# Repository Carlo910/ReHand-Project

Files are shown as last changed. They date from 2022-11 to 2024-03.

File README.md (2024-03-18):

# AY2223_I_Project-3

Re-Hand Versione 1.0 13/02/2023

***
Short Description:

Re-Hand is a device that uses 4 flex sensors, mounted on a glove, to recognize gestures. It is designed to be used in rehabilitation, to train subjects who experience problems in perfoming the "grasping" movement. Rehabilitation is done through repetition of the "grasping" gesture by playing a game by carrying out precise instructions given on the screen.
Breve descrizione:

Itlian version: 
Re-Hand è un dispositivo che utilizza 4 flex sensors, montati su di un guanto, per riconoscere dei gesti. 
E' stato pensato per essere utilizzato in ambito riabilitativo, per allenare soggetti che riscontrano problemi nel perfomare il
movimento del "grasping". 
La riabilitazione viene effettuata tramite la ripetizione del gesto del "grasping" svolgendo un gioco eseguendo precise istruzioni fornite a schermo. 

***

Hardware:

A glove is used on which four flex sensors, from thumb to ring finger, are sewn onto the top of the fingers. To read the value measured by the sensors, four voltage dividers (one for each sensor) were made with four 2 kOhm resistors. A PSoC 5LP Dev Kit CY8CKIT-059 was used as the microcontroller. The device was designed as a wearable, so it is equipped with a bluetooth module for sensor data communication and a 3.7 V lipo battery for power supply, with an attached charging circuit.  A 3.3 V linear stabilizer was added to provide the microcontroller with a stabilized voltage, while the Bluetooth gets an unstabilized voltage since the minimum voltage required to power it is 3.6 V.
To check the battery charge level, two identical 1 kOhm resistors were added to read the drop voltage across them.
After prototyping the device, a PCB was made into which all components were soldered. See the 'Eagle' folder to view the model made for printing the PCB.  A case was made thanks to a 3D printer to contain all the hardware components (apart from the sensors and glove). In the 'SolidWorks' folder you can find the model made for printing. It is possible to conveniently turn the device on and off by pressing a switch on the top side of the case. To monitor the bluetooth connection, the user can refer to a red LED located on the side of the case, which flashes at a frequency of 0.2 Hz during bluetooth connection and turns solid once the connection is successfully occurred.

***
PsoC Creator 
The Psoc Creator IDE (Integrated Design Environment) was used to develop the project from the firmware side. 
Within the 'PSOC' folder can be found the 'Project3' workspace which contains the 'Project3' project where the code used to sample the data, average it and finally send it via Bluetooth to the connected device. 
For data sampling, the frequency of the interrupt timer was set to 10 Hz. Once a piece of data is received, it waits to have 10 samples in order to average them and then send them. In addition, every minute the
the battery charge value and then sent. Also managed within the code is the Bluetooth connection and its Led to display whether it has taken place (Led on) or not (Led flashes at 0.2 Hz). In addition, there is the project 'Project3_dataset' which was used to build the datasets for the development of the classifier. A different code is used to make data collection easier by simplifying the connection with the  device that receives the data.

***

Python

To use Re-Hand you need version 3.9 with various libraries to install on your virtual enviroment.
See the file 'requirements.txt' in the folder and run it in your virtual  
environment to install all the required libraries with their respective versions.
 
Upon launching the GUI.py code, the name of the Re-Hand project appears on the screen and the user will be asked to enter their name, thanks to which it will be possible to save performance data from different users. Next, the user can click  a start button, which allows the start of sampling the values of the four variable resistors. In case the user has not entered the name, he/she will not be able to access the second screen and an error message will be displayed on asscreen. Once the start button is pressed, a new screen is opened where the user can choose whether to play the game, or display on the screen some statistical data on the improvement in playing it. 

Thanks to a classifier, specifically a Random Forest, the device can recognize six gestures in total, three used to move through the different GUI windows and three for the rehabilitation task. In the file 'classification_6gestures.ipynb' it is possible to see how the model used for the classification of the gestures. The files 'dataset_training_6gesti.csv' and 'dataset_test_6gesti.csv' contain all the data used to
train and test the model which were collected using the code 'code_dataset.py'. In the file 'rf_model_6gesti.pkl' is saved the model trained on the datasets mentioned above and used to perform real-time prediction for gesture recognition while using the application.

By raising only the index finger (target 4), one enters the game window. At this point the user can start performing the gesture
of grasping, starting with the hand fully open (target 0), then trying to close it halfway (target 1) and finally closing the fist completely (target 2). While performing these gestures, the user will be able to see on the screen an image of a bow being drawn, progressively as the hand closes, until an arrow is fired. Once the game is finished, the time it took the user to complete the gesture is printed on the screen. In the event that the exercise is not performed correctly (time taken longer than 30 seconds) a message will be displayed on the screen a message inviting the user to exit the game and try again. By raising only the thumb while keeping the hand closed (target 3), you will exit the game screen and return to the main Home screen. 

At this point, by raising both index and average (target 5) you can enter the statistics screen, where a graph can be displayed on the screen showing the times in seconds in which the user has done the last ten exercises, if any, with the respective date so that any improvements can be visualized. The display of statistics is allowed only if the user has completed the game at least twice, otherwise an error message appears on the screen. The following graph also shows failed attempts by reporting a time of 30 seconds (the maximum attainable value), highlighted on the graph by a red line. The user's best result, absolute worst result (in case of success) and the number of failed attempts are also displayed. By raising only the thumb while keeping the hand closed (target 3), you exit the game screen to return to the main Home screen. 

***

Italian version:

Hardware:
Si utilizza un guanto su cui sono cuciti quattro flex sensors, dal pollice all'anulare, sulla parte superiore delle dita. Per leggere
il valore misurato dai sensori sono stati realizzati 4 partitori di tensione (uno per ogni sensore) con 4 resistenze da 2 kOhm.
Come microcontrollore è stato usato un PSoC 5LP Dev Kit CY8CKIT‐059.  
Il device è stato pensato come wearble, per cui è dotato di modulo bluetooth per la comunicazione dei dati dei sensori e di una batteria lipo a 3.7 V per
l'alimentazione, con annesso circuito di ricarica. 
E' stato aggiunto uno stabilizzatore lineare a 3.3 V per fornire al microcontrollore una tensione stabilizzata, mentre al modulo
bluetooth arriva una tensione non stabilizzata poichè la minima tensione richiesta per alimentarlo è di 3.6 V.
Per controllare il livello di carica della batteria sono state aggiunte due resistenze identiche da 1 kOhm per leggere la caduta
di tensione su di esse.
Dopo aver realizzato il dispositivo in via prototipale è stata realizzata una PCB in cui sono stati saldati tutti i componenti.
Vedere la cartella 'Eagle' per visualizzare il modello realizzato per la stampa della PCB. 
Per contenere tutti i componenti hardware (a parte i sensori e guanto) è stato realizzato un case grazie ad una stampante 3D. Nella
cartella 'SolidWorks' è possibile trovare la realizzazione del modello per la stampa.
E' possibile accendere e spegnere comodamente il dispositivo premendo un interruttore posto sul lato superiore del case.
Per monitorare la connessione del bluetooth, l'utente può fare riferimento a un led rosso posizionato lateralmente al case, il quale
lampeggia a una frequenza di 0,2 Hz durante la connessione del bluetooth e diventa fisso una volta che la connessione è correttamente
avvenuta.

***

PsoC Creator 
E' stato utilizzato il Psoc Creator IDE (Integrated Design Environment) per sviluppare il progetto dal lato firmware. 
All'interno della cartella 'PSOC' si può trovare il workspace 'Project3' il quale contiene il progetto 'Project3' dove si trova il 
codice utilizzato per campionare i dati, mediarli e infine inviarli tramite Bluetooth al dispositivo connesso. 
Per il campionamento dei dati è stata impostata la frequenza del timer dell'interrupt a 10 Hz. Una volta ricevuto un dato si attende
di avere 10 campioni per poter calcolare la media di questi ultimi e successivamente inviarli. In aggiunta ogni minuto viene misurato
il valore di carica della batteria e poi inviato.
All'interno del codice è gestita anche la connessione del Bluetooth e il relativo Led per visualizzare se è avvenuta (Led acceso)
oppure no (Led lampeggia a 0,2 Hz).
Inoltre è presente il progetto 'Project3_dataset' il quale è stato usato per la realizzazione dei dataset per lo sviluppo del 
classificatore. Viene usato un codice diverso per rendere la raccolta dei dati più agevole semplificando la connessione con il 
dispositivo che riceve i dati.

***

Python

Per utilizzare Re-Hand è necessaria la versione 3.9 con varie librerie da installare sul prorpio virtual enviroment.
Vedere nella cartella il file 'requirements.txt' e eseguirlo nel prorpio virtual  
environment per installare tutte le librerie necessarie con le rispettive versioni.
 
Lanciando il codice GUI.py appare a schermo il nome del progetto Re-Hand e verrà chiesto all'utente di inserire il proprio 
nome, grazie al quale sarà possibile salvare i dati delle prestazioni di diversi utenti. In seguito l'utente può cliccare 
un pulsante di start, che permette l'inizio del campionamento dei valori delle quattro resistenze variabili.
Nel caso in cui l'utente non abbia inserito il nome, non potrà accedere alla seconda schermata e verrà visualizzato a aschermo un messaggio di errore.
Una volta premuto il pulsante di start, viene aperta una nuova schermata dove l'utente può scegliere se svolgere il gioco, 
oppure visualizzare a schermo alcuni dati statistici sul miglioramento nello svolgimento dello stesso.

Grazie a un classificatore, in particolare un Random Forest, il dispositivo riesce a riconoscere sei gesti in totale,
tre utilizzati per muoversi attraverso le diverse finestre della GUI e tre per l'attività di riabilitazione.
Nel file 'classification_6gesti.ipynb' è possibile visualizzare come è stato realizzato il modello usato per la
classificatione dei gesti. I files 'dataset_training_6gesti.csv' e 'dataset_test_6gesti.csv' contengono tutti i dati usati per
allenare e testare il modello i quali sono stati raccolti utilizzando il codice 'codice_dataset.py'. Nel file 'rf_model_6gesti.pkl' è
salvato il modello allenato sui dataset citati sopra e usato per compiere la predizione i tempo reale per il riconoscimento dei gesti
durante l'utilizzo dell'applicazione.

Alzando solo l'indice (target 4), si entra nella finestra del gioco. A questo punto l'utente può iniziare a performare il gesto
del grasping, partendo con la mano completamente aperta (target 0), provando poi a chiuderla a metà (target 1) e infine
chiudendo completamente il pugno (target 2). Durante l'esecuzione di questi gesti, l'utente potrà visualizzare a schermo
l'immagine di un arco che viene tirato, progressivamente alla chiusura della mano, fino a scoccare una freccia. 
Una volta finito il gioco viene stampato a schermo il tempo che l'utente ha impiegato per completare il gesto.
Nel caso in cui l'esercizio non venga svolto correttamente (tempo di svolgimento superiore a 30 secondi) verrà visualizzato 
a schermo un messaggio che inviterà l'utente a uscire dal gioco e a riprovare. Alzano solo il pollice mantenendo la mano chiusa
(target 3), si esce dalla schermata del gioco per tornare nella schermata Home principale. 
 
A questo punto, alzando sia indice che medio (target 5) è possibile entrare nella schermata delle statistiche,
dove si può visualizzare a schermo un grafico che mostra i tempi in secondi in cui l'utente ha svolto gli ultimi dieci l'esercizi, se presenti, con la rispettiva
data in modo da poter visualizzare gli eventuali miglioramenti. La visualizzazione delle statistiche viene permessa solo se
l'utente ha completato almeno due volte il gioco, in caso contrario appare a schermo un messaggio di errore.
Il seguente grafico inoltre mostra anche i tentativi falliti riportando un tempo di 30 secondi (il massimo valore raggiungibile),
evidenziato sul grafico da una linea rossa.
Vengono inoltre visualizzati il risultato migliore, quello peggiore in assoluto dell'utente (in caso di successo) e il numero di tentativi falliti.
Alzano solo il pollice mantenendo la mano chiusa
(target 3), si esce dalla schermata del gioco per tornare nella schermata Home principale.

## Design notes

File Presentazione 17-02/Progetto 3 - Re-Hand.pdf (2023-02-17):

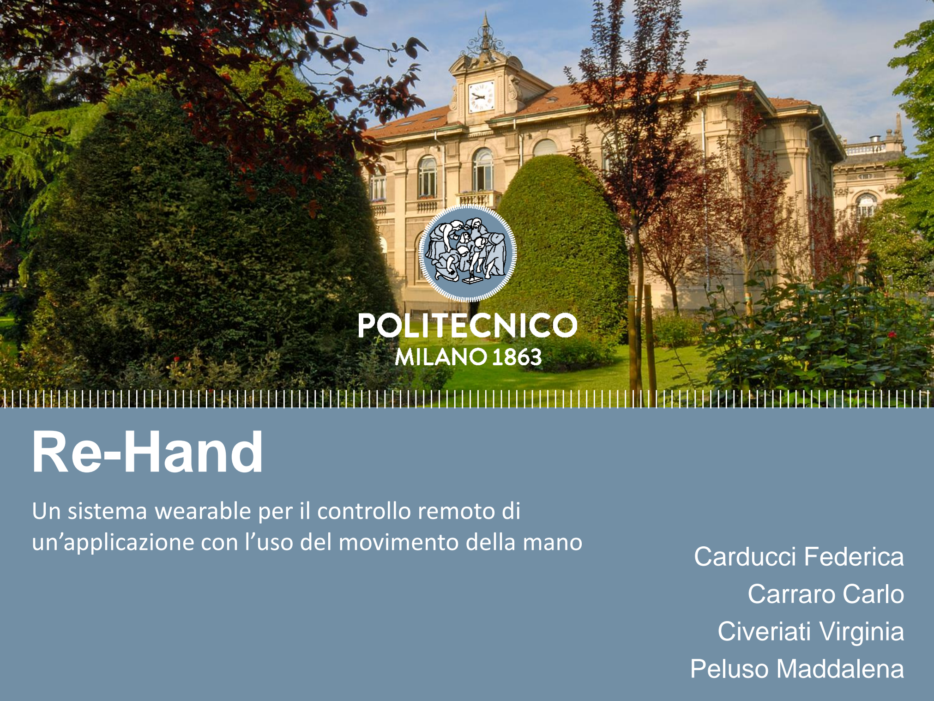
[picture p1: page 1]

# Titolo presentazione sottotitolo

# Milano, XX mese 20XX

# Re-Hand

## Carducci Federica Carraro Carlo Civeriati Virginia Peluso Maddalena

# Un sistema wearable per il controllo remoto di un’applicazione con l’uso del movimento della mano

# STATO DELL’ARTE

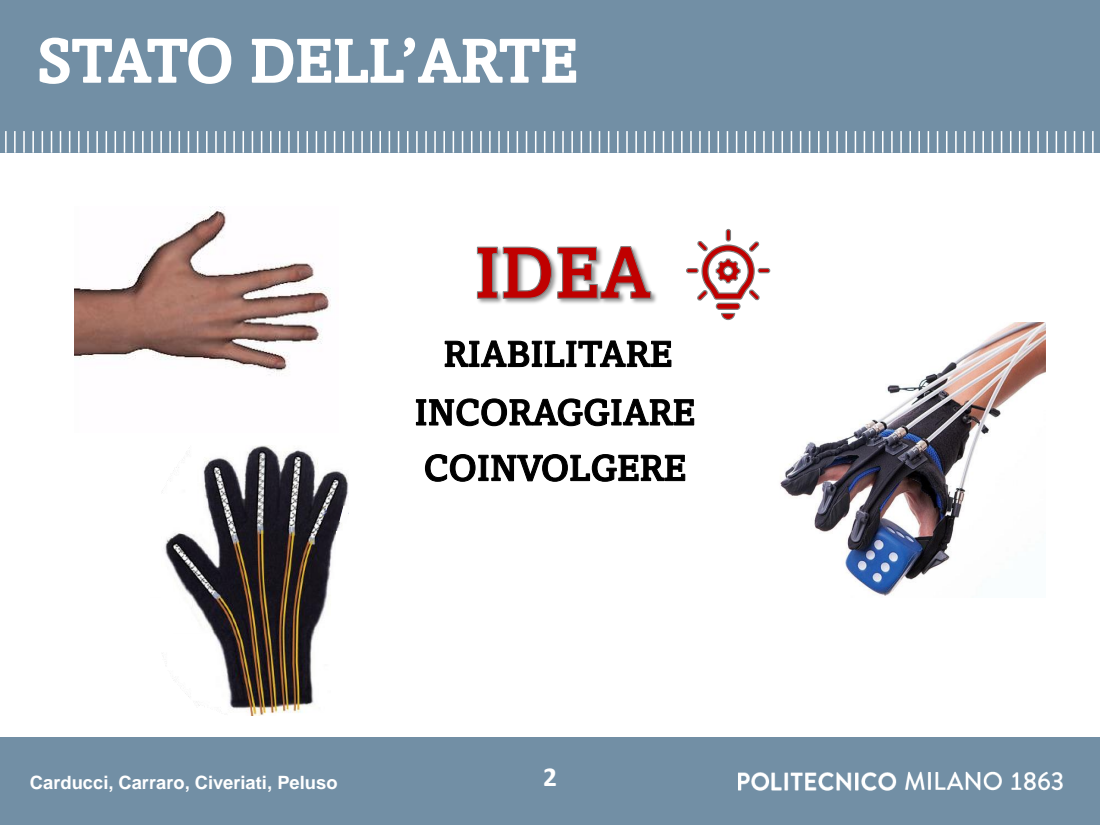
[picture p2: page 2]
Carducci, Carraro, Civeriati, Peluso; RIABILITARE; INCORAGGIARE; COINVOLGERE

# STATO DELL’ARTE

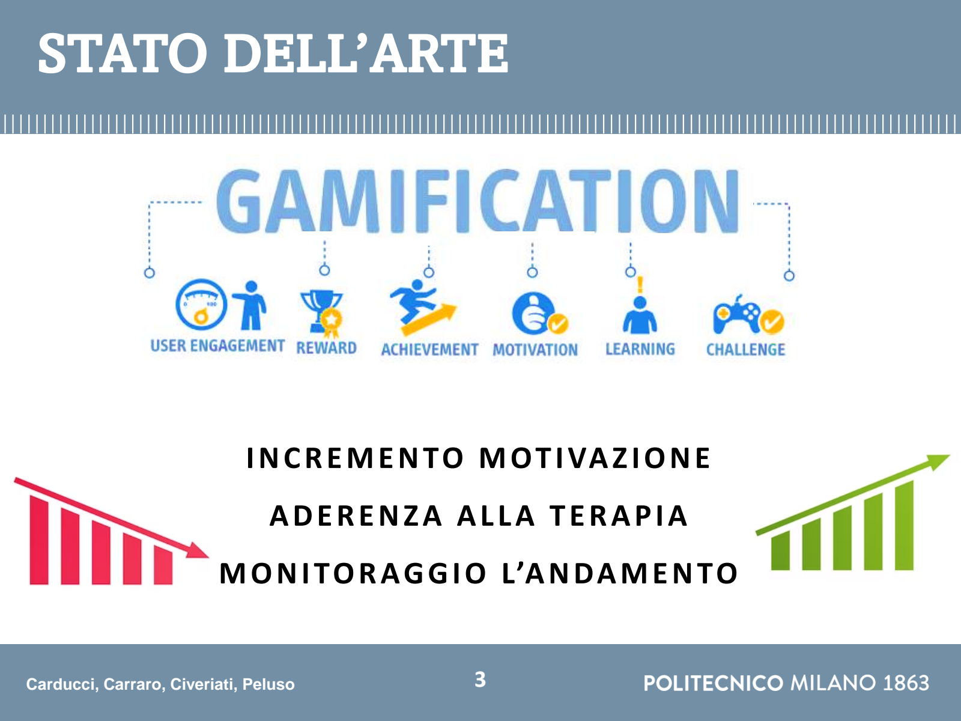
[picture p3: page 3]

Carducci, Carraro, Civeriati, Peluso | 3

# I N C R E M E N TO M OT I VA Z I O N E

# A D E R E N Z A A L L A T E R A P I A

# M O N I TO R A G G I O L’A N DA M E N TO

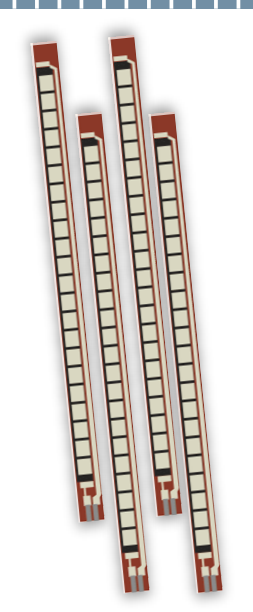
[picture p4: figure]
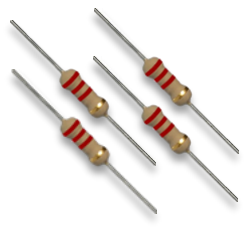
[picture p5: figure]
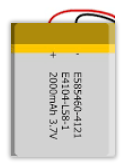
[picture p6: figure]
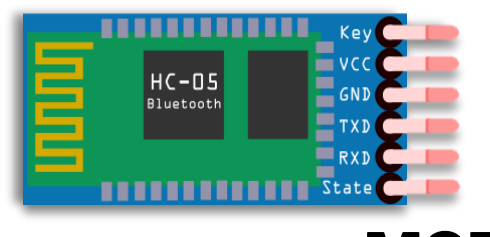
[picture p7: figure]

Carducci, Carraro, Civeriati, Peluso | 4

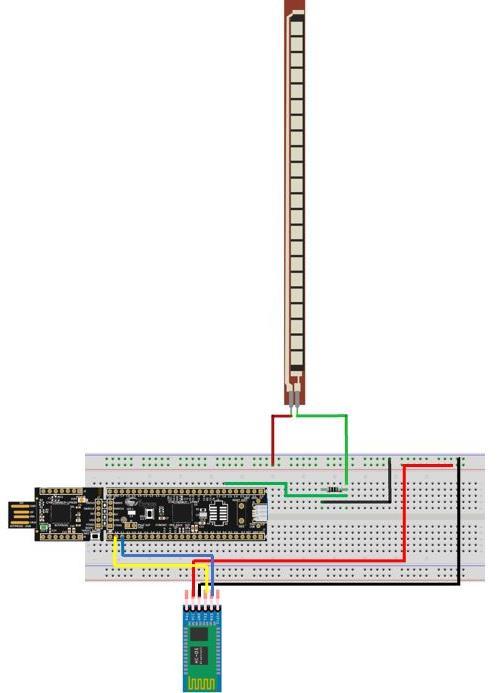
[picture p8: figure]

## 4 x FLEX SENSOR

## 4 x 2 KOhm

## MODULO BLUETOOTH

## BATTERIA

3.7 V

## E CIRCUITO DI RICARICA

## STABILIZZATORE LINEARE (MCP1826S)

## LED

## INTERRUTORE

# COMPONENTI HARDWARE

# COMPONENTI HARDWARE

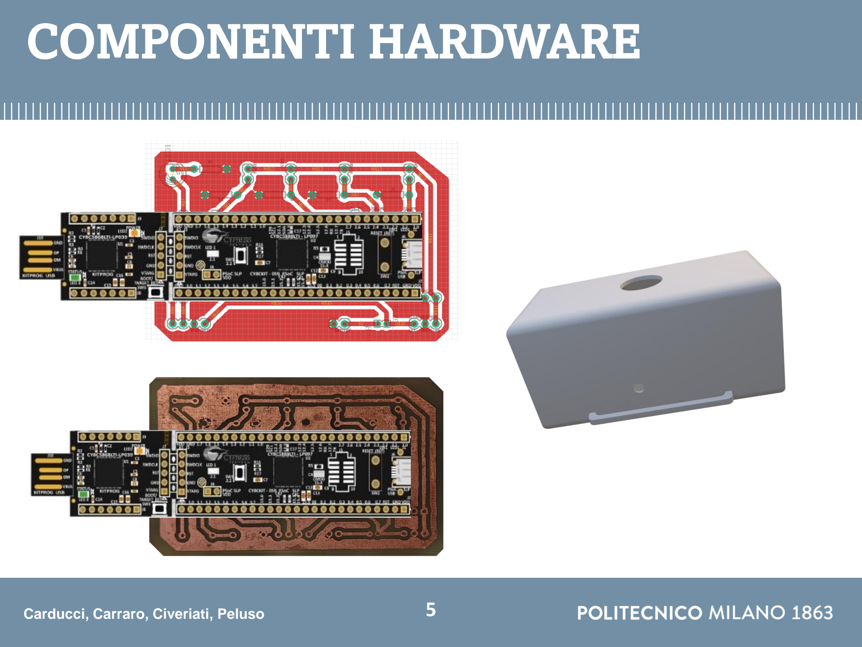
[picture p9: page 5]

Carducci, Carraro, Civeriati, Peluso | 5

# COMPONENTI HARDWARE

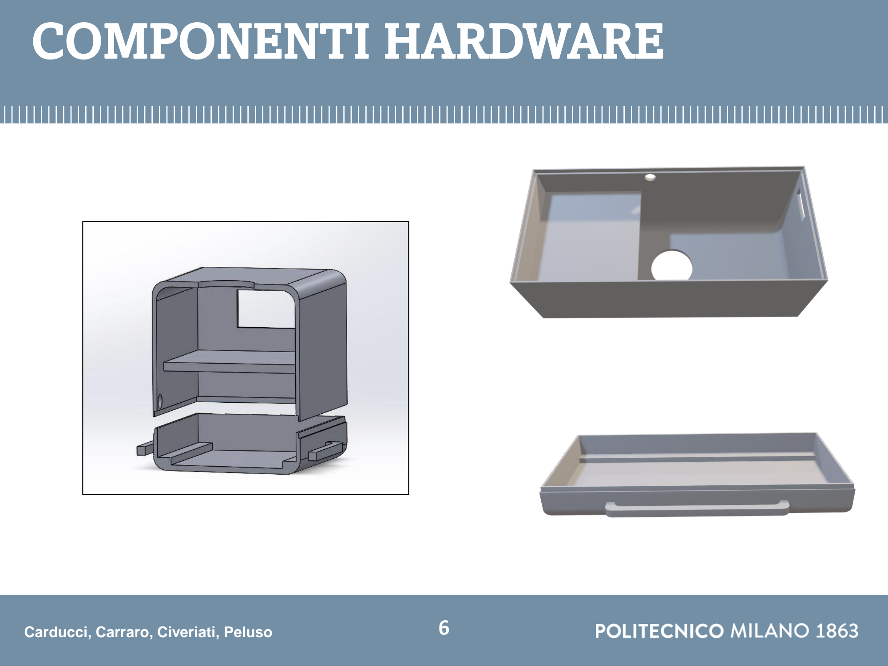
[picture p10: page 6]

Carducci, Carraro, Civeriati, Peluso | 6

## SENSORI

# DATI

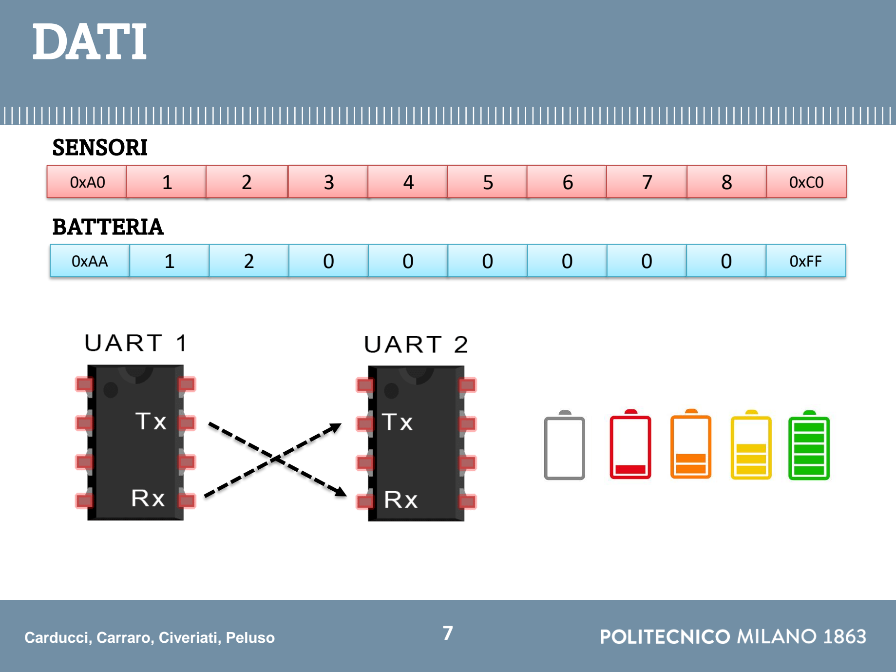
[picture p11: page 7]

Carducci, Carraro, Civeriati, Peluso

1 | 2 | 3 | 4

7

0xA0 | 1 | 2 | 3 | 4 | 5 | 6 | 7 | 8 | 0xC0
0xAA | 1 | 2 | 0 | 0 | 0 | 0 | 0 | 0 | 0xFF

## BATTERIA

# RANDOM FOREST

# PREDIZIONE

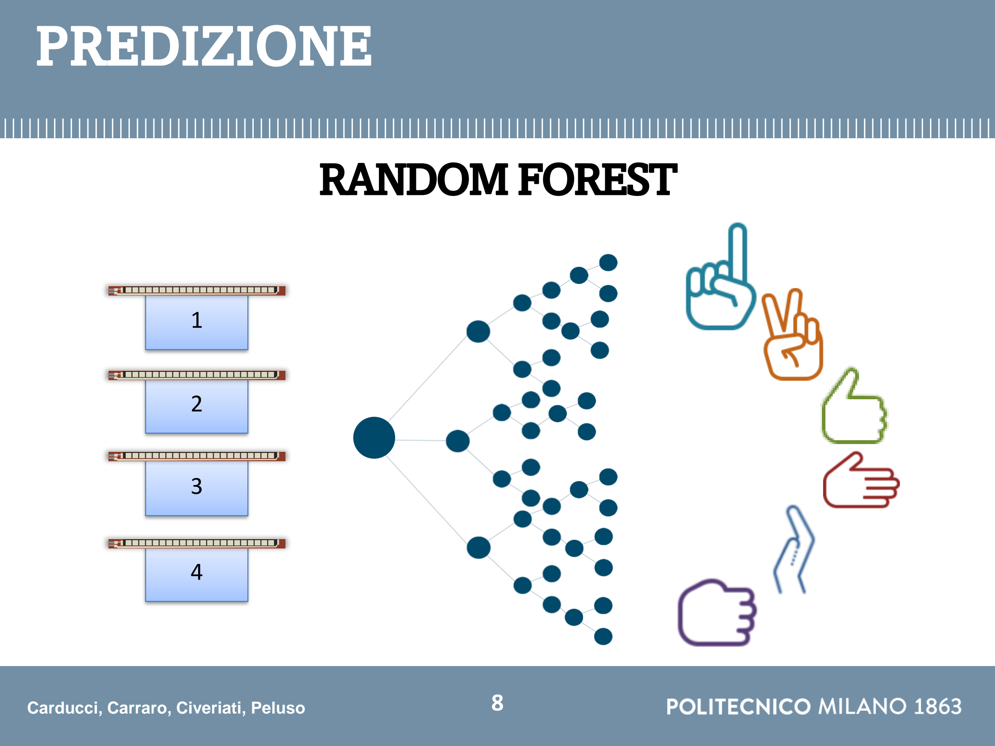
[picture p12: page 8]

Carducci, Carraro, Civeriati, Peluso | 8

1

2

3

4

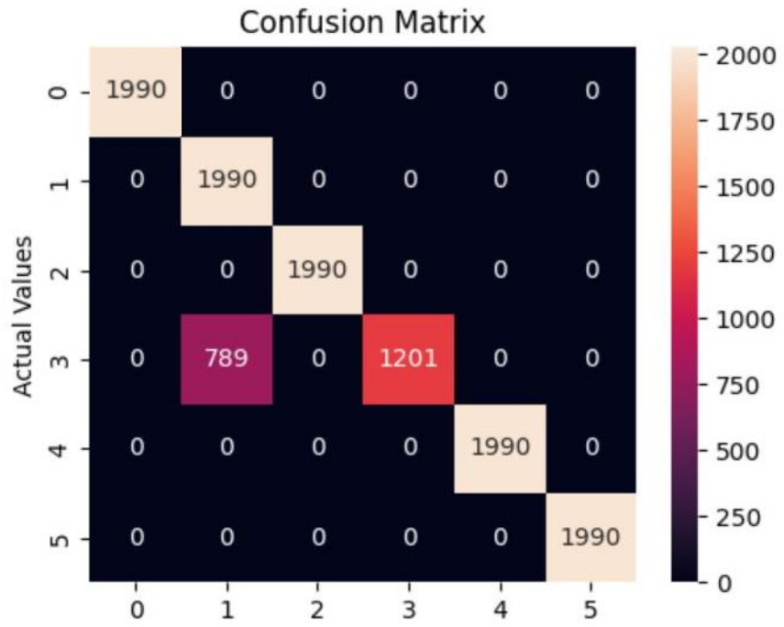
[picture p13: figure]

Carducci, Carraro, Civeriati, Peluso | 9

## Solo due gesti vengono confusi tra loro

# RISULTATI

# RANDOM FOREST

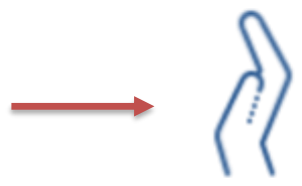
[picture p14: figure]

# GUI

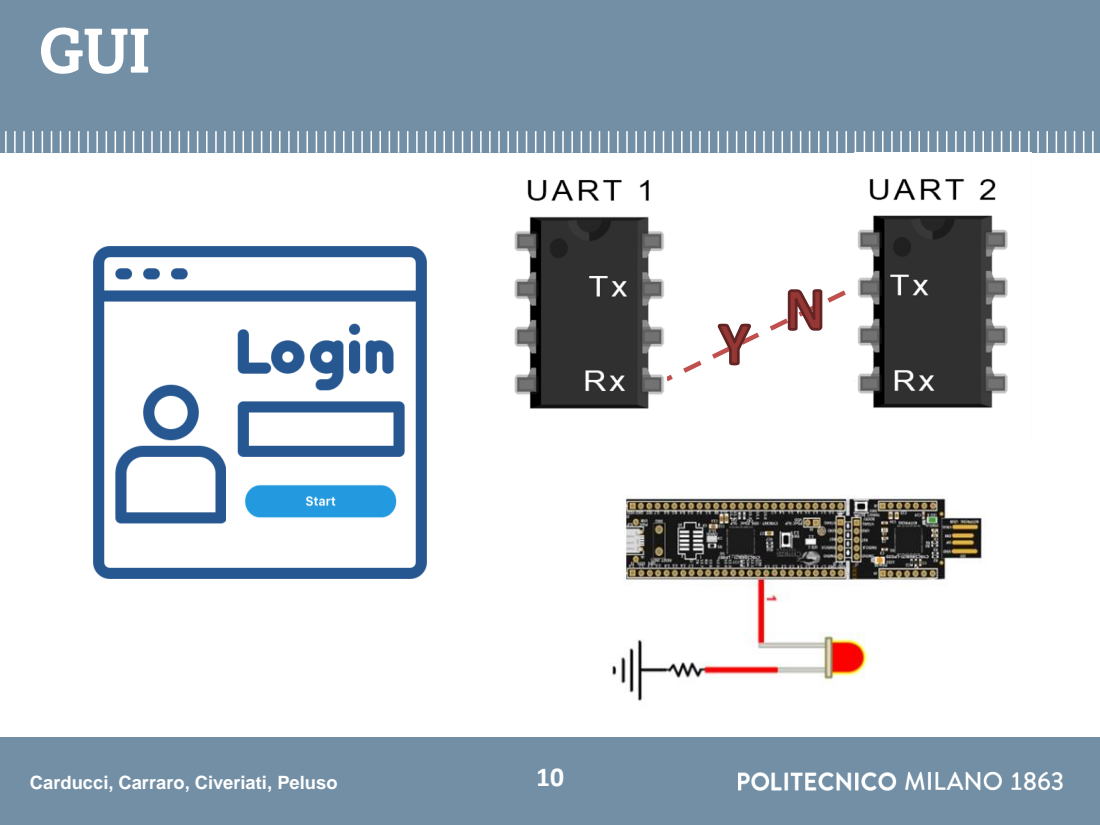
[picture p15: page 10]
Carducci, Carraro, Civeriati, Peluso

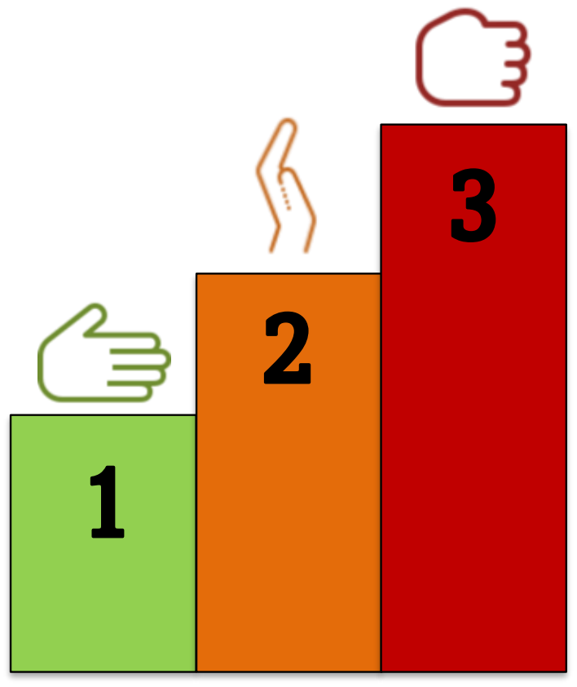
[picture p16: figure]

Carducci, Carraro, Civeriati, Peluso | 11

# DINAMICHE DEL GIOCO

# GUI

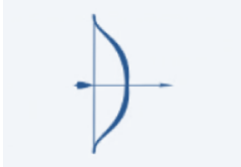
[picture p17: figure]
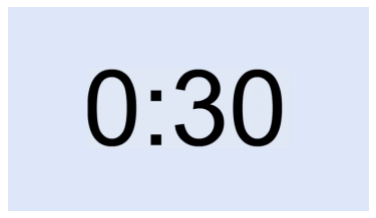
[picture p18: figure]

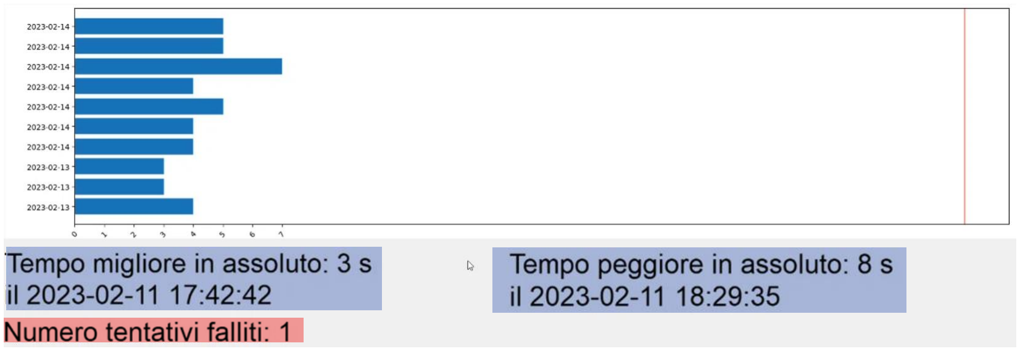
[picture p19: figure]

Carducci, Carraro, Civeriati, Peluso | 12

# STATISTICHE DELL’UTENTE

# GUI

# SVILUPPI FUTURI

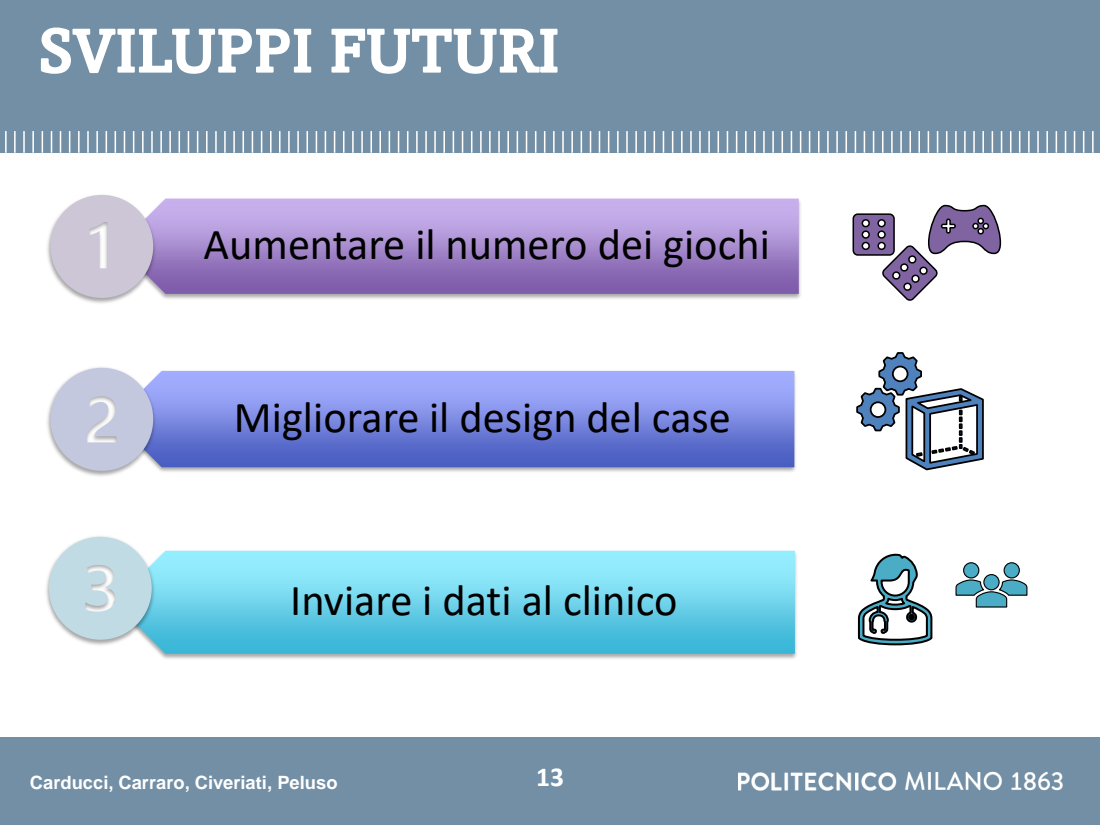
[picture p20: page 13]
Carducci, Carraro, Civeriati, Peluso

Aumentare il numero dei giochi

Migliorare il design del case

Inviare i dati al clinico

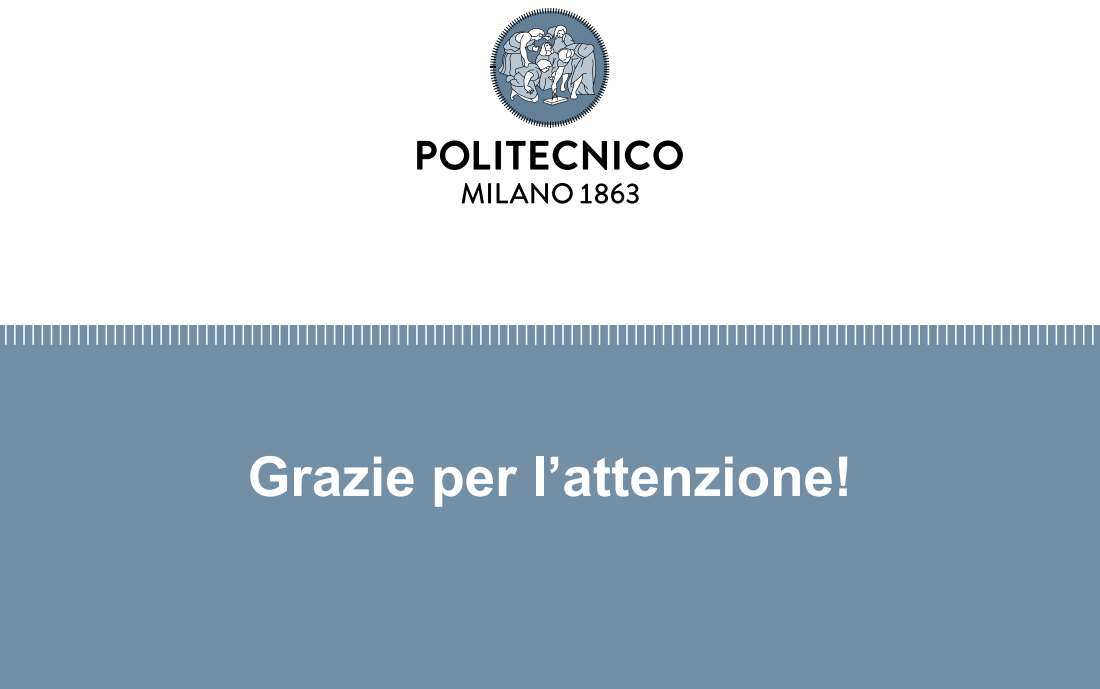
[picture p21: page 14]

Grazie per l’attenzione!

# DEMO

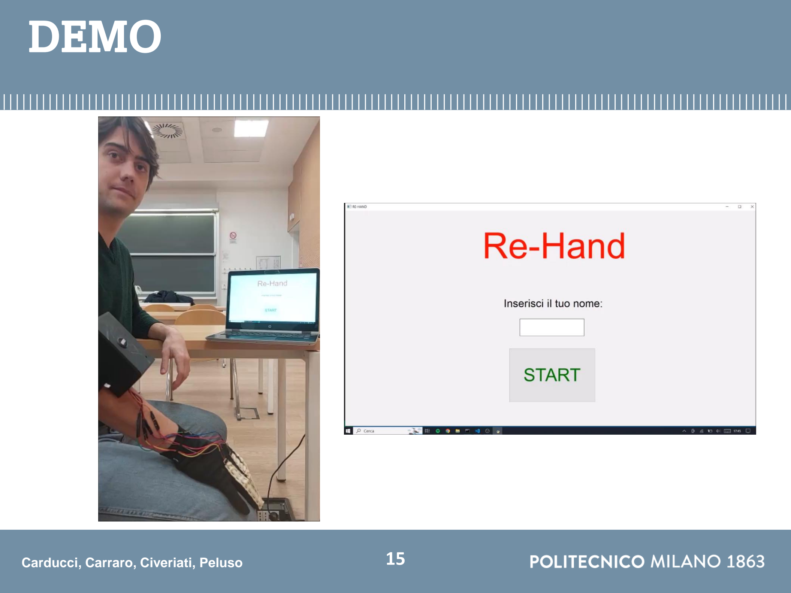
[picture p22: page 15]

Carducci, Carraro, Civeriati, Peluso | 15

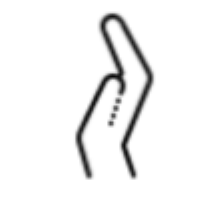
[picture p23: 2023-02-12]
PYTHON/Immagini/mano2.png

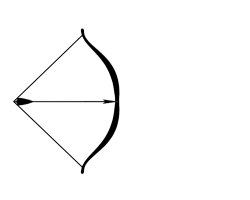
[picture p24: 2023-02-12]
PYTHON/Immagini/arco2.png

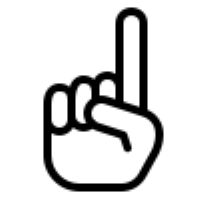
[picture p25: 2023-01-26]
PYTHON/Immagini/indice.png

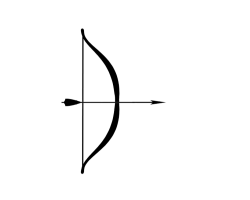
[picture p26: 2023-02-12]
PYTHON/Immagini/arco1.png

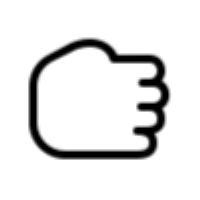
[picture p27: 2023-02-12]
PYTHON/Immagini/mano3.png

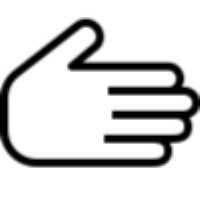
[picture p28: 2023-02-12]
PYTHON/Immagini/mano1.png

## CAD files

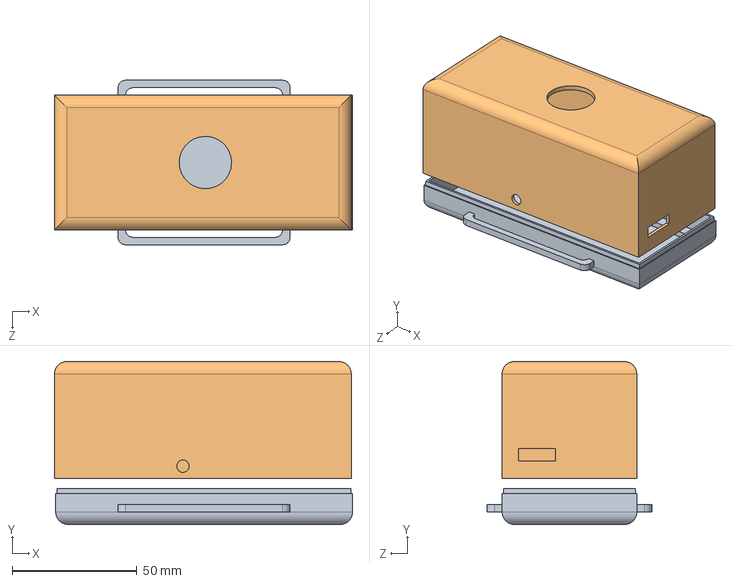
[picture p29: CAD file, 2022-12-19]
SolidWorks/Assieme1.SLDASM
119.5 x 65.4 x 66.0 mm
Case-BOTTOM
Case-TOP

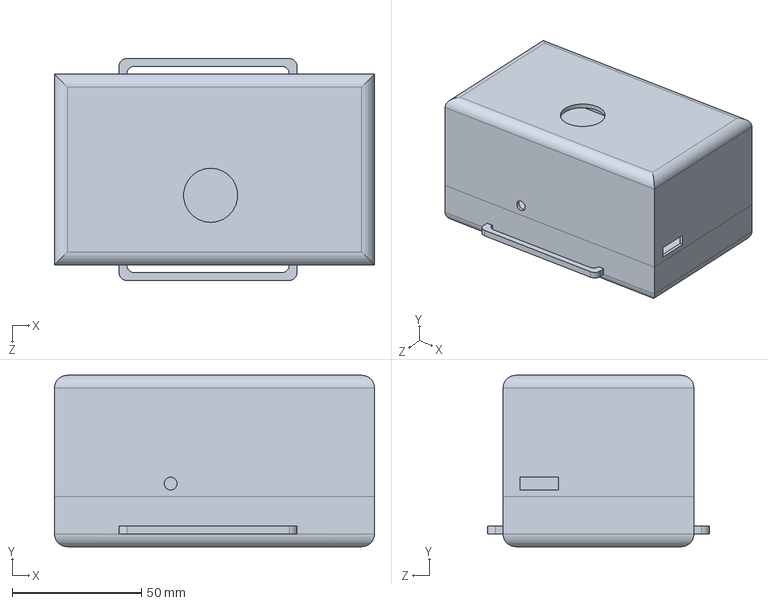
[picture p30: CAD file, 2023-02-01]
SolidWorks/Case.SLDPRT
124.0 x 66.5 x 86.0 mm

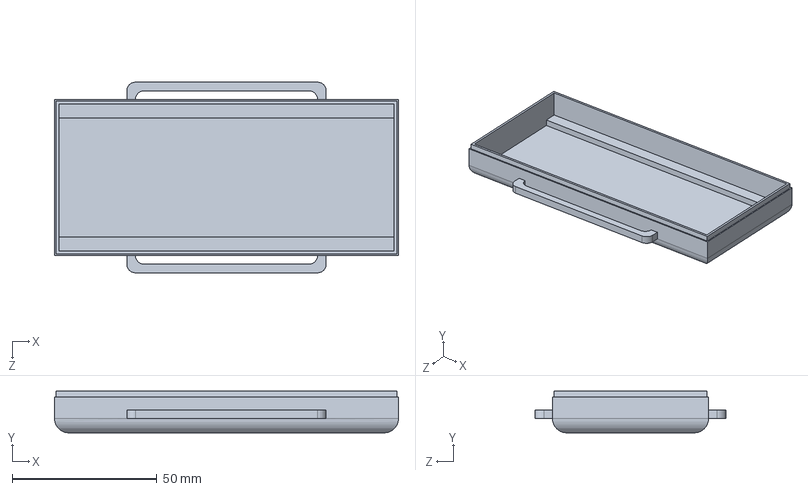
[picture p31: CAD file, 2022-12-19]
SolidWorks/Case-BOTTOM.SLDPRT
119.0 x 14.5 x 66.0 mm

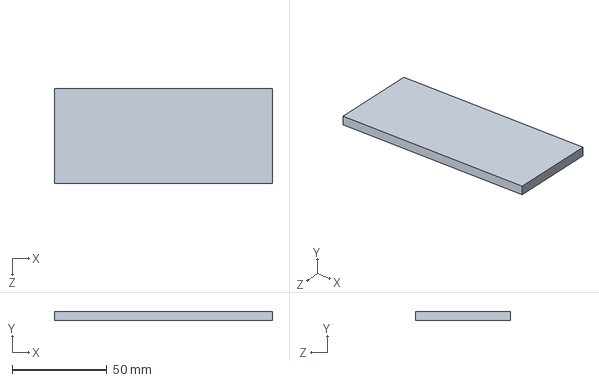
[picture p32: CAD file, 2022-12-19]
SolidWorks/Case-PCB.SLDPRT
115.0 x 5.00 x 50.0 mm

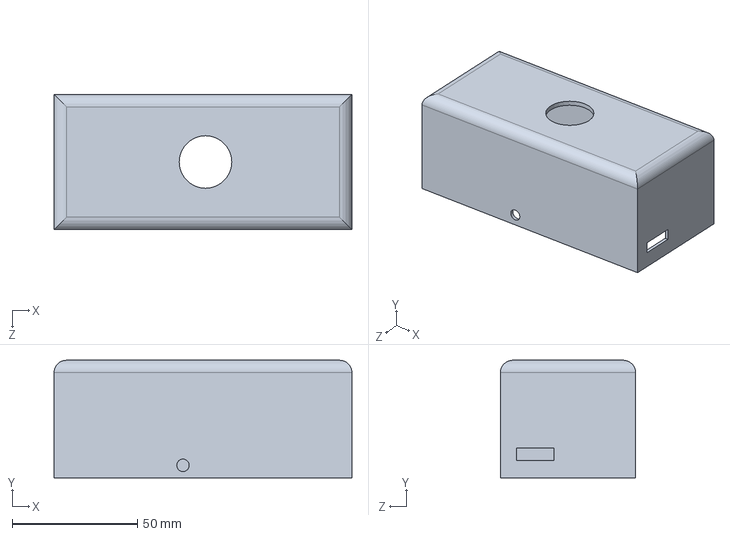
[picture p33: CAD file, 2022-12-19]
SolidWorks/Case-TOP.SLDPRT
119.0 x 47.0 x 54.0 mm

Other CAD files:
SolidWorks/Case-BOTTOM.3MF
SolidWorks/Case-TOP.3MF
SolidWorks/Case.3MF

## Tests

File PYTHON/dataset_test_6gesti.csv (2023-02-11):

dito1 | dito2 | dito3 | dito4 | target
3881 | 4290 | 5662 | 3628 | 0
3881 | 4290 | 5662 | 3628 | 0
3889 | 4295 | 5682 | 3631 | 0
3889 | 4295 | 5682 | 3631 | 0
3899 | 4297 | 5690 | 3632 | 0
3899 | 4297 | 5690 | 3632 | 0
3907 | 4299 | 5691 | 3633 | 0
3907 | 4299 | 5691 | 3633 | 0
3919 | 4301 | 5693 | 3637 | 0
3919 | 4301 | 5693 | 3637 | 0
3925 | 4305 | 5700 | 3641 | 0
3925 | 4305 | 5700 | 3641 | 0
3946 | 4322 | 5684 | 3657 | 0
3946 | 4322 | 5684 | 3657 | 0
3940 | 4311 | 5701 | 3645 | 0
3940 | 4311 | 5701 | 3645 | 0
3943 | 4312 | 5714 | 3641 | 0
3943 | 4312 | 5714 | 3641 | 0
3948 | 4314 | 5709 | 3643 | 0
3948 | 4314 | 5709 | 3643 | 0
3954 | 4315 | 5716 | 3647 | 0
3954 | 4315 | 5716 | 3647 | 0
3960 | 4319 | 5730 | 3655 | 0
3960 | 4319 | 5730 | 3655 | 0
3964 | 4323 | 5723 | 3657 | 0
3964 | 4323 | 5723 | 3657 | 0
3967 | 4327 | 5718 | 3659 | 0
3967 | 4327 | 5718 | 3659 | 0
3968 | 4328 | 5723 | 3662 | 0
3968 | 4328 | 5723 | 3662 | 0
3973 | 4332 | 5727 | 3665 | 0
3973 | 4332 | 5727 | 3665 | 0
3975 | 4339 | 5743 | 3670 | 0
3975 | 4339 | 5743 | 3670 | 0
3970 | 4350 | 5739 | 3679 | 0
3970 | 4350 | 5739 | 3679 | 0
3971 | 4361 | 5747 | 3686 | 0
3971 | 4361 | 5747 | 3686 | 0
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

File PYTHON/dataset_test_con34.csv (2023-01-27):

dito1 | dito2 | dito3 | dito4 | target
4686 | 4422 | 4566 | 3242 | 0
4686 | 4422 | 4566 | 3242 | 0
4689 | 4445 | 4590 | 3260 | 0
4689 | 4445 | 4590 | 3260 | 0
4691 | 4456 | 4601 | 3267 | 0
4691 | 4456 | 4601 | 3267 | 0
4693 | 4472 | 4611 | 3273 | 0
4693 | 4472 | 4611 | 3273 | 0
4695 | 4486 | 4627 | 3283 | 0
4695 | 4486 | 4627 | 3283 | 0
4697 | 4495 | 4632 | 3292 | 0
4697 | 4495 | 4632 | 3292 | 0
4700 | 4504 | 4644 | 3300 | 0
4700 | 4504 | 4644 | 3300 | 0
4700 | 4508 | 4648 | 3306 | 0
4700 | 4508 | 4648 | 3306 | 0
4699 | 4514 | 4654 | 3310 | 0
4699 | 4514 | 4654 | 3310 | 0
4701 | 4519 | 4659 | 3313 | 0
4701 | 4519 | 4659 | 3313 | 0
4704 | 4519 | 4655 | 3301 | 0
4704 | 4519 | 4655 | 3301 | 0
4707 | 4513 | 4655 | 3244 | 0
4707 | 4513 | 4655 | 3244 | 0
4703 | 4534 | 4672 | 3265 | 0
4703 | 4534 | 4672 | 3265 | 0
4422 | 4310 | 4486 | 3091 | 0
4422 | 4310 | 4486 | 3091 | 0
4394 | 4144 | 4327 | 3048 | 0
4394 | 4144 | 4327 | 3048 | 0
4436 | 4603 | 4706 | 3587 | 0
4436 | 4603 | 4706 | 3587 | 0
4448 | 4123 | 4328 | 3011 | 0
4448 | 4123 | 4328 | 3011 | 0
4463 | 4296 | 4437 | 3164 | 0
4463 | 4296 | 4437 | 3164 | 0
4471 | 4365 | 4517 | 3419 | 0
4471 | 4365 | 4517 | 3419 | 0
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

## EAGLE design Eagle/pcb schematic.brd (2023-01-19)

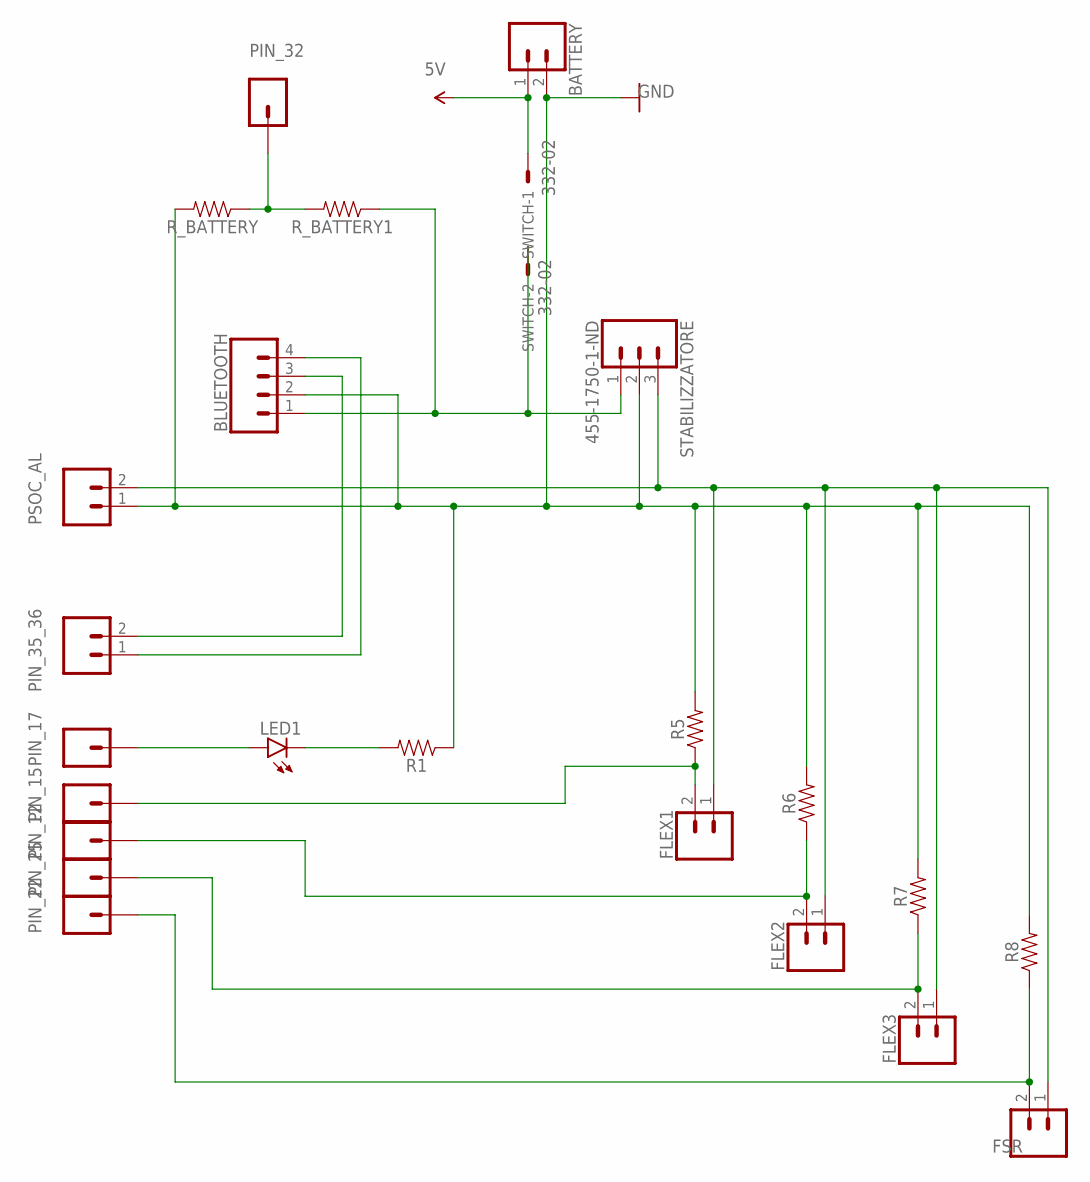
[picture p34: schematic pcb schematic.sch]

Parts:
BATTERY: CONN_02; 1X02
BLUETOOTH: CONN_04; 1X04
FLEX1, FLEX2, FLEX3: CONN_02; 1X02
FSR: CONN_02; 1X02
LED1: LED5MM
PIN_12, PIN_15, PIN_17, PIN_22, PIN_25, PIN_32: CONN_01; 1X01
PIN_35_36: CONN_02; 1X02
PSOC_AL: CONN_02; 1X02
R1, R5, R6, R7, R8: AXIAL-0.3
R_BATTERY, R_BATTERY1: AXIAL-0.3
STABILIZZATORE: 455-1750-1-ND; 1X03
SWITCH: 332-02

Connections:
5V: BATTERY.1, SWITCH.1
GND: BATTERY.2, BLUETOOTH.2, PSOC_AL.1, R1.P$1 (1), R5.P$2 (2), R6.P$2 (2), R7.P$2 (2), R8.P$2 (2), R_BATTERY.P$2 (2), STABILIZZATORE.2
unnamed: FLEX1.2, PIN_15.1, R5.P$1 (1)
unnamed: FLEX2.2, PIN_12.1, R6.P$1 (1)
unnamed: FLEX3.2, PIN_25.1, R7.P$1 (1)
unnamed: BLUETOOTH.3, PIN_35_36.2
unnamed: FSR.2, PIN_22.1, R8.P$1 (1)
unnamed: BLUETOOTH.4, PIN_35_36.1
unnamed: LED1.A, PIN_17.1
unnamed: LED1.K (C), R1.P$2 (2)
unnamed: PIN_32.1, R_BATTERY.P$1 (1), R_BATTERY1.P$2 (2)
unnamed: BLUETOOTH.1, R_BATTERY1.P$1 (1), STABILIZZATORE.1, SWITCH.2
unnamed: FLEX1.1, FLEX2.1, FLEX3.1, FSR.1, PSOC_AL.2, STABILIZZATORE.3

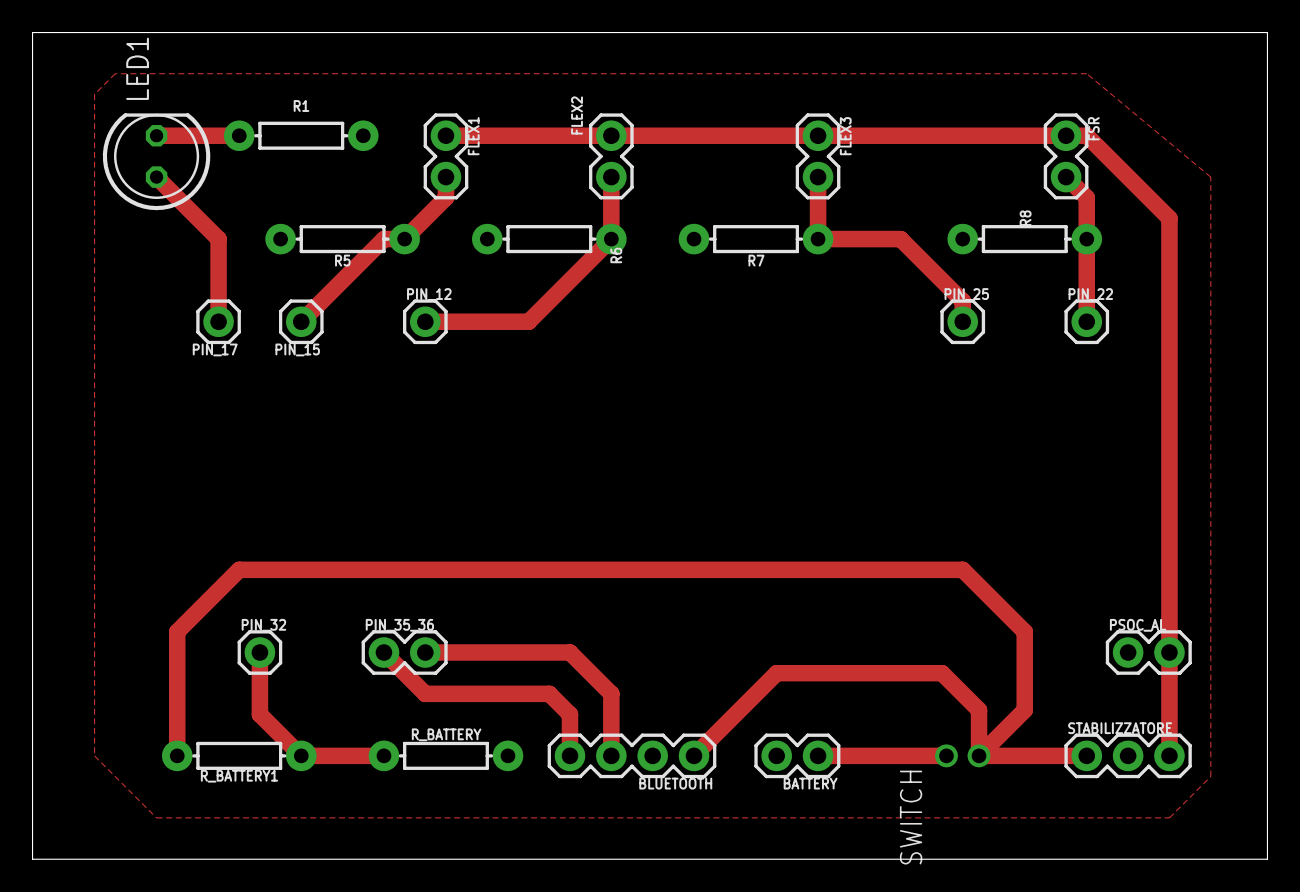
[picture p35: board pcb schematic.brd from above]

Board: 2 copper layers, 75.9 x 50.8 mm, 24 parts (1 on the bottom side), 13 nets.

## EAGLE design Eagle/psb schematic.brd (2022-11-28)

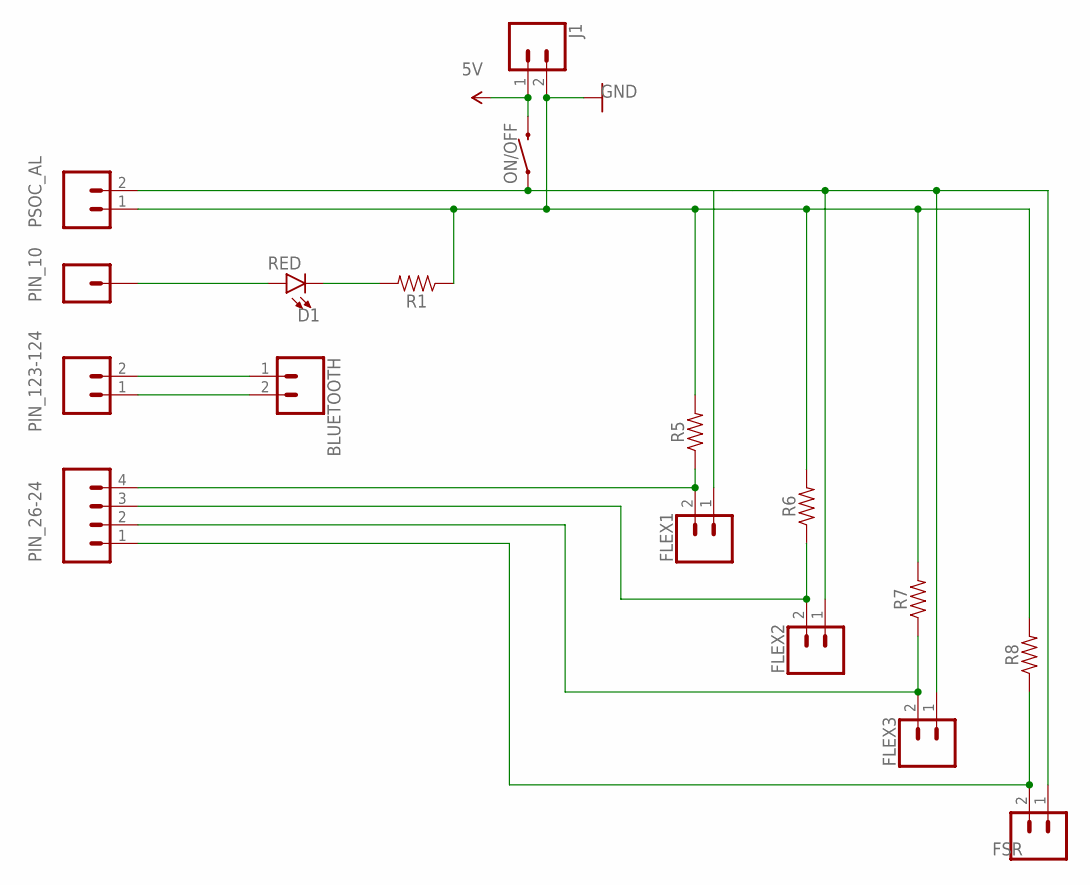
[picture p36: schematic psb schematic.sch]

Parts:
BLUETOOTH: CONN_02; 1X02
D1: RED; LED-0603
FLEX1, FLEX2, FLEX3: CONN_02; 1X02
FSR: CONN_02; 1X02
J1: CONN_02; 1X02
ON/OFF: MOMENTARY-SWITCH-SPST-SMD-6.0X3.5MM; TACTILE_SWITCH_SMD_6.0X3.5MM
PIN_10: CONN_01; 1X01
PIN_26-24: CONN_04; 1X04
PIN_123-124: CONN_02; 1X02
PSOC_AL: CONN_02; 1X02
R1, R5, R6, R7, R8: AXIAL-0.3

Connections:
5V: J1.1, ON/OFF.2
GND: J1.2, PSOC_AL.1, R1.P$1 (1), R5.P$2 (2), R6.P$2 (2), R7.P$2 (2), R8.P$2 (2)
unnamed: FLEX1.2, PIN_26-24.4, R5.P$1 (1)
unnamed: FLEX2.2, PIN_26-24.3, R6.P$1 (1)
unnamed: FLEX3.2, PIN_26-24.2, R7.P$1 (1)
unnamed: BLUETOOTH.1, PIN_123-124.2
unnamed: FSR.2, PIN_26-24.1, R8.P$1 (1)
unnamed: BLUETOOTH.2, PIN_123-124.1
unnamed: FLEX1.1, FLEX2.1, FLEX3.1, FSR.1, ON/OFF.1, PSOC_AL.2
unnamed: D1.A, PIN_10.1
unnamed: D1.C, R1.P$2 (2)

Board: 2 copper layers, 17 parts (0 on the bottom side), 11 nets, no tracks yet.

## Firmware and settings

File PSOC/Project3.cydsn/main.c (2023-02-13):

/* ========================================
 * PROGETTO 3
 * RE-HAND 
 * 
 * ========================================
*/
#include "project.h"
#include "stdio.h"
#include "Interrupt_Routines.h"

#define LED_ON 1
#define LED_OFF 0

char Received = 'N';

int main(void)
{
    CyGlobalIntEnable; 

    /* Inizializzazione ADC, UART, TIMER e ISR */
    ADC_DelSig_Start();
    UART_Start();
    UART_BT_Start();
    Timer_Start();
    isr_ADC_StartEx(Custom_ISR_ADC);
    //Inizializzazione Flag per la gestione invio dati
    PacketReadyFlag = 0;
    PacketReadyFlag1 = 0;
    //Inzio Conversione ADC e MUX
    ADC_DelSig_StartConvert();
    AMux_Start();
    
    //Header e Tail dei pacchetti dati sensori e batteria
    DataBuffer[0] = 0xA0;
    DataBuffer[TRANSMIT_BUFFER_SIZE-1] = 0xC0;
    DataBuffer1[0] = 0xAA;
    DataBuffer1[TRANSMIT_BUFFER_SIZE-1] = 0xFF;
    led_status = LED_OFF;
    
    for(;;)
    {
        // Gestione lampeggio led se il bluetooth non è connesso
        if(led_status == LED_OFF)
        {
            Pin_LED_Write(LED_ON);
            CyDelay(500);
            Pin_LED_Write(LED_OFF);
            CyDelay(500);
        }
        else
        {
            Pin_LED_Write(LED_ON);
        }
    
        // Se il bluetooth è collegato il led è fisso e i dati vengono inviati
        if(led_status == LED_ON){
        
        if ( PacketReadyFlag==1){
            for(int8 i=0; i<2; i++){
             // Comunicazione con BT dati sensori
             UART_BT_PutArray(DataBuffer, TRANSMIT_BUFFER_SIZE );
            }
        PacketReadyFlag=0;
        } if(PacketReadyFlag1==1){
            //Comunicazione con BT dati batteria 
             UART_BT_PutArray(DataBuffer1, TRANSMIT_BUFFER_SIZE);
            PacketReadyFlag1=0;
        }
    }
  }
}

/* FINE */

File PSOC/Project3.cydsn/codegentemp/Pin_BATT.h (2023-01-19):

/*******************************************************************************
* File Name: Pin_BATT.h  
* Version 2.20
*
* Description:
*  This file contains Pin function prototypes and register defines
*
* Note:
*
********************************************************************************
* Copyright 2008-2015, Cypress Semiconductor Corporation.  All rights reserved.
* You may use this file only in accordance with the license, terms, conditions, 
* disclaimers, and limitations in the end user license agreement accompanying 
* the software package with which this file was provided.
*******************************************************************************/

#if !defined(CY_PINS_Pin_BATT_H) /* Pins Pin_BATT_H */
#define CY_PINS_Pin_BATT_H

#include "cytypes.h"
#include "cyfitter.h"
#include "cypins.h"
#include "Pin_BATT_aliases.h"

/* APIs are not generated for P15[7:6] */
#if !(CY_PSOC5A &&\
	 Pin_BATT__PORT == 15 && ((Pin_BATT__MASK & 0xC0) != 0))


/***************************************
*        Function Prototypes             
***************************************/    

/**
* \addtogroup group_general
* @{
*/
void    Pin_BATT_Write(uint8 value);
void    Pin_BATT_SetDriveMode(uint8 mode);
uint8   Pin_BATT_ReadDataReg(void);
uint8   Pin_BATT_Read(void);
void    Pin_BATT_SetInterruptMode(uint16 position, uint16 mode);
uint8   Pin_BATT_ClearInterrupt(void);
/** @} general */

/***************************************
*           API Constants        
***************************************/
/**
* \addtogroup group_constants
* @{
*/
    /** \addtogroup driveMode Drive mode constants
     * \brief Constants to be passed as "mode" parameter in the Pin_BATT_SetDriveMode() function.
     *  @{
     */
        #define Pin_BATT_DM_ALG_HIZ         PIN_DM_ALG_HIZ
        #define Pin_BATT_DM_DIG_HIZ         PIN_DM_DIG_HIZ
        #define Pin_BATT_DM_RES_UP          PIN_DM_RES_UP
        #define Pin_BATT_DM_RES_DWN         PIN_DM_RES_DWN
        #define Pin_BATT_DM_OD_LO           PIN_DM_OD_LO
        #define Pin_BATT_DM_OD_HI           PIN_DM_OD_HI
        #define Pin_BATT_DM_STRONG          PIN_DM_STRONG
        #define Pin_BATT_DM_RES_UPDWN       PIN_DM_RES_UPDWN
    /** @} driveMode */
/** @} group_constants */
    
/* Digital Port Constants */
#define Pin_BATT_MASK               Pin_BATT__MASK
#define Pin_BATT_SHIFT              Pin_BATT__SHIFT
#define Pin_BATT_WIDTH              1u

/* Interrupt constants */
#if defined(Pin_BATT__INTSTAT)
/**
* \addtogroup group_constants
* @{
*/
    /** \addtogroup intrMode Interrupt constants
     * \brief Constants to be passed as "mode" parameter in Pin_BATT_SetInterruptMode() function.
     *  @{
     */
        #define Pin_BATT_INTR_NONE      (uint16)(0x0000u)
        #define Pin_BATT_INTR_RISING    (uint16)(0x0001u)
        #define Pin_BATT_INTR_FALLING   (uint16)(0x0002u)
        #define Pin_BATT_INTR_BOTH      (uint16)(0x0003u) 
    /** @} intrMode */
/** @} group_constants */

    #define Pin_BATT_INTR_MASK      (0x01u) 
#endif /* (Pin_BATT__INTSTAT) */


/***************************************
*             Registers        
***************************************/

/* Main Port Registers */
/* Pin State */
#define Pin_BATT_PS                     (* (reg8 *) Pin_BATT__PS)
/* Data Register */
#define Pin_BATT_DR                     (* (reg8 *) Pin_BATT__DR)
/* Port Number */
#define Pin_BATT_PRT_NUM                (* (reg8 *) Pin_BATT__PRT) 
/* Connect to Analog Globals */                                                  
#define Pin_BATT_AG                     (* (reg8 *) Pin_BATT__AG)                       
/* Analog MUX bux enable */
#define Pin_BATT_AMUX                   (* (reg8 *) Pin_BATT__AMUX) 
/* Bidirectional Enable */                                                        
#define Pin_BATT_BIE                    (* (reg8 *) Pin_BATT__BIE)
/* Bit-mask for Aliased Register Access */
#define Pin_BATT_BIT_MASK               (* (reg8 *) Pin_BATT__BIT_MASK)
/* Bypass Enable */
#define Pin_BATT_BYP                    (* (reg8 *) Pin_BATT__BYP)
/* Port wide control signals */                                                   
#define Pin_BATT_CTL                    (* (reg8 *) Pin_BATT__CTL)
/* Drive Modes */
#define Pin_BATT_DM0                    (* (reg8 *) Pin_BATT__DM0) 
#define Pin_BATT_DM1                    (* (reg8 *) Pin_BATT__DM1)
#define Pin_BATT_DM2                    (* (reg8 *) Pin_BATT__DM2) 
/* Input Buffer Disable Override */
#define Pin_BATT_INP_DIS                (* (reg8 *) Pin_BATT__INP_DIS)
/* LCD Common or Segment Drive */
#define Pin_BATT_LCD_COM_SEG            (* (reg8 *) Pin_BATT__LCD_COM_SEG)
/* Enable Segment LCD */
#define Pin_BATT_LCD_EN                 (* (reg8 *) Pin_BATT__LCD_EN)
/* Slew Rate Control */
#define Pin_BATT_SLW                    (* (reg8 *) Pin_BATT__SLW)
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

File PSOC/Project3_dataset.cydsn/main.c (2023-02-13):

/* ========================================
 * PROGETTO 3
 * RE-HAND 
 * Codice per la creazione del dataset
 * ========================================
*/
#include "project.h"
#include "stdio.h"
#include "Interrupt_Routines.h"


int main(void)
{
    CyGlobalIntEnable; 

    /* Inizializzazione ADC, UART, TIMER e ISR */
    ADC_DelSig_Start();
    UART_Start();
    UART_BT_Start();
    Timer_Start();
    isr_ADC_StartEx(Custom_ISR_ADC);
    //Inizializzazione Flag per la gestione invio dati
    PacketReadyFlag = 0;
    //Inzio Conversione ADC e MUX
    ADC_DelSig_StartConvert();
    AMux_Start();
    
    //Header e Tail dei pacchetti dati sensori
    DataBuffer[0] = 0xA0;
    DataBuffer[TRANSMIT_BUFFER_SIZE-1] = 0xC0;
    
    for(;;)
    {
       if ( PacketReadyFlag==1){
            //Invio dati
            for(int8 i=0; i<2; i++){
             //comunicazione UART
             UART_PutArray(DataBuffer, TRANSMIT_BUFFER_SIZE );
            }
        PacketReadyFlag=0;
        } 
    }
}

/* FINE */

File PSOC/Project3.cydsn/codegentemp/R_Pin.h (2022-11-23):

/*******************************************************************************
* File Name: R_Pin.h  
* Version 2.20
*
* Description:
*  This file contains Pin function prototypes and register defines
*
* Note:
*
********************************************************************************
* Copyright 2008-2015, Cypress Semiconductor Corporation.  All rights reserved.
* You may use this file only in accordance with the license, terms, conditions, 
* disclaimers, and limitations in the end user license agreement accompanying 
* the software package with which this file was provided.
*******************************************************************************/

#if !defined(CY_PINS_R_Pin_H) /* Pins R_Pin_H */
#define CY_PINS_R_Pin_H

#include "cytypes.h"
#include "cyfitter.h"
#include "cypins.h"
#include "R_Pin_aliases.h"

/* APIs are not generated for P15[7:6] */
#if !(CY_PSOC5A &&\
	 R_Pin__PORT == 15 && ((R_Pin__MASK & 0xC0) != 0))


/***************************************
*        Function Prototypes             
***************************************/    

/**
* \addtogroup group_general
* @{
*/
void    R_Pin_Write(uint8 value);
void    R_Pin_SetDriveMode(uint8 mode);
uint8   R_Pin_ReadDataReg(void);
uint8   R_Pin_Read(void);
void    R_Pin_SetInterruptMode(uint16 position, uint16 mode);
uint8   R_Pin_ClearInterrupt(void);
/** @} general */

/***************************************
*           API Constants        
***************************************/
/**
* \addtogroup group_constants
* @{
*/
    /** \addtogroup driveMode Drive mode constants
     * \brief Constants to be passed as "mode" parameter in the R_Pin_SetDriveMode() function.
     *  @{
     */
        #define R_Pin_DM_ALG_HIZ         PIN_DM_ALG_HIZ
        #define R_Pin_DM_DIG_HIZ         PIN_DM_DIG_HIZ
        #define R_Pin_DM_RES_UP          PIN_DM_RES_UP
        #define R_Pin_DM_RES_DWN         PIN_DM_RES_DWN
        #define R_Pin_DM_OD_LO           PIN_DM_OD_LO
        #define R_Pin_DM_OD_HI           PIN_DM_OD_HI
        #define R_Pin_DM_STRONG          PIN_DM_STRONG
        #define R_Pin_DM_RES_UPDWN       PIN_DM_RES_UPDWN
    /** @} driveMode */
/** @} group_constants */
    
/* Digital Port Constants */
#define R_Pin_MASK               R_Pin__MASK
#define R_Pin_SHIFT              R_Pin__SHIFT
#define R_Pin_WIDTH              1u

/* Interrupt constants */
#if defined(R_Pin__INTSTAT)
/**
* \addtogroup group_constants
* @{
*/
    /** \addtogroup intrMode Interrupt constants
     * \brief Constants to be passed as "mode" parameter in R_Pin_SetInterruptMode() function.
     *  @{
     */
        #define R_Pin_INTR_NONE      (uint16)(0x0000u)
        #define R_Pin_INTR_RISING    (uint16)(0x0001u)
        #define R_Pin_INTR_FALLING   (uint16)(0x0002u)
        #define R_Pin_INTR_BOTH      (uint16)(0x0003u) 
    /** @} intrMode */
/** @} group_constants */

    #define R_Pin_INTR_MASK      (0x01u) 
#endif /* (R_Pin__INTSTAT) */


/***************************************
*             Registers        
***************************************/

/* Main Port Registers */
/* Pin State */
#define R_Pin_PS                     (* (reg8 *) R_Pin__PS)
/* Data Register */
#define R_Pin_DR                     (* (reg8 *) R_Pin__DR)
/* Port Number */
#define R_Pin_PRT_NUM                (* (reg8 *) R_Pin__PRT) 
/* Connect to Analog Globals */                                                  
#define R_Pin_AG                     (* (reg8 *) R_Pin__AG)                       
/* Analog MUX bux enable */
#define R_Pin_AMUX                   (* (reg8 *) R_Pin__AMUX) 
/* Bidirectional Enable */                                                        
#define R_Pin_BIE                    (* (reg8 *) R_Pin__BIE)
/* Bit-mask for Aliased Register Access */
#define R_Pin_BIT_MASK               (* (reg8 *) R_Pin__BIT_MASK)
/* Bypass Enable */
#define R_Pin_BYP                    (* (reg8 *) R_Pin__BYP)
/* Port wide control signals */                                                   
#define R_Pin_CTL                    (* (reg8 *) R_Pin__CTL)
/* Drive Modes */
#define R_Pin_DM0                    (* (reg8 *) R_Pin__DM0) 
#define R_Pin_DM1                    (* (reg8 *) R_Pin__DM1)
#define R_Pin_DM2                    (* (reg8 *) R_Pin__DM2) 
/* Input Buffer Disable Override */
#define R_Pin_INP_DIS                (* (reg8 *) R_Pin__INP_DIS)
/* LCD Common or Segment Drive */
#define R_Pin_LCD_COM_SEG            (* (reg8 *) R_Pin__LCD_COM_SEG)
/* Enable Segment LCD */
#define R_Pin_LCD_EN                 (* (reg8 *) R_Pin__LCD_EN)
/* Slew Rate Control */
#define R_Pin_SLW                    (* (reg8 *) R_Pin__SLW)
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

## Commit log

2022-11-21 Lettura di tutti i sensori per determinare la threshold
2022-11-21 Ordine cartella
    [Valori_Sens.xlsx]
2022-11-21 Inizio PCB
    [psb schematic.brd, psb schematic.sch]
2022-11-23 modifica codice Psoc e Python
    [Project3!.sdf]
2022-11-28 codice di lettura con menu per la scelta della porta seriale
2022-11-28 modifica file psoc
    [Project3!.sdf]
2022-11-28 Correzioni PCB
    [psb schematic.brd, psb schematic.sch]
2022-11-28 PCB finita
    [pcb schematic.brd, pcb schematic.sch]
2022-11-28 lettura di 10 bytes
2022-11-30 Prova controllo packets
    [Project3!.sdf]
2022-11-30 ordine dei sensori
    [Valori_Sens.xlsx]
2022-11-30 tentativo di combinare i codici
2022-11-30 Aggiunta bluetooth e passaggio valori attraverso i thread
2022-12-02 PCB modifica tracce e aggiunta componenti batteria
    [pcb schematic.brd, pcb schematic.sch]
2022-12-02 PCB con pin separati senza errori
    [pcb schematic.brd, pcb schematic.sch]
2022-12-04 Creato folder per il case e inizio progettazione
    [Case.SLDPRT]
2022-12-04 Correzioni psoc
    [Project3!.sdf]
2022-12-04 Nuovo codice per la creazione del dataset
    [dataset.csv]
2022-12-06 Correzione bluetooth Psoc
    [Project3!.sdf]
2022-12-06 prima prova dataset
    [dataset.csv]
2022-12-07 rete neurale con dataset per il training e per il test
    [dataset.csv, dataset_test.csv, dataset_training.csv]
2022-12-09 aggiunta di altra finestra, pulsanti quadrati
2022-12-16 Case quasi finito. Mancano alcuni fori.
    [BOTTOM.SLDPRT, Case.SLDPRT, PCB.SLDPRT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]
2022-12-16 Nuovo codice per la grafica
2022-12-16 inizio modello per la classificazione
2022-12-18 modifica handle_packet
    [Project3!.sdf]
2022-12-19 case finito + modifica pcb
    [Assieme1.SLDASM, BOTTOM.SLDPRT, Case-BOTTOM.3MF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]
2022-12-19 Modifica pcb + case finito
    [Project3!.sdf]
2022-12-19 Creazione dataset più grande e training, salvataggio e predizione con modello salvato
    [dataset_test.csv, dataset_training.csv]
2022-12-20 Implementato random forest e prova LSTM
    [Project3!.sdf, dataset_test.csv]
2022-12-20 pulsanti con scritte e quarta schermata
    [dataset_test.csv]
2022-12-29 nuovo dataset con pollice in posizione correttae rete modificata per meno dati
    [dataset_training_new.csv]
2022-12-30 test set con pollice alzato
    [dataset_test_new.csv, dataset_training_new.csv]
2023-01-05 immagini per i pulsanti e inizio del gioco
    [dataset_training_new.csv]
2023-01-05 Inizio grafico statistiche
    [Project3!.sdf]
2023-01-09 RF con dataset nuovo
    [dataset_training_new.csv]
2023-01-10 prova con bluetooth nuovo
    [Project3!.sdf]
2023-01-11 codice del psoc modificato con l'introduzione del LED e modifiche nel codice python
    [Project3!.sdf]
2023-01-19 aggiunta lettura carica batteria
    [Project3!.sdf]
2023-01-19 PCB con aggiunta resistenze per carica batteria
    [pcb schematic.brd, pcb schematic.sch]
2023-01-19 problemi Led connessione
2023-01-23 Modifica psoc led lampeggia, calcolo batteria modificato, nuove immagini
    [Project3!.sdf]
2023-01-24 aggiunta modello nel codice python
    [Project3!_Copy_01.sdf, dataset_training_new.csv]
2023-01-26 Avanzamento e modifiche gioco
    [Project3!.sdf, Project3!_Copy_01.sdf, dataset_test_new.csv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]
2023-01-27 aggiunta modello per predizione in tempo reale
    [dataset_test_new.csv, dataset_training_new.csv]
2023-01-29 aggiunta dataset con gesto 1 e 2 e aggiunto a iniziogui
    [dataset_training_new.csv]
2023-02-01 modifica case solidworks, mancano solo i fori per le viti
    [Case.SLDPRT]
2023-02-02 nuovo layout
    [Project3!.sdf]
2023-02-03 Modifica modello classificazione
    [dataset_test.csv, dataset_test_con34.csv, dataset_test_senza34.csv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]
2023-02-03 Nuova grafica, introduzione delle tempistiche di esecuzione e del pulsante di uscita
2023-02-04 Icone per la batteria e aggiornamento layout del gioco
2023-02-07 Introduzione statistiche e rigistro dato
    [data_register.csv]
2023-02-08 modifica grafico statistiche, rimangono problemi con le date
    [data_register.csv]
2023-02-09 modello nuovo
    [Project3!.sdf, Project3!_Copy_01.sdf, dataset_test_pollice.csv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]
2023-02-09 aggiunta modello con gesto pollice
    [data_register.csv, dataset_test_pollice.csv, dataset_training_pollice.csv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]
2023-02-10 Grafico finito
    [data_register.csv]
2023-02-11 tempo migliore e peggiore
    [data_register.csv, dataset_training_6gesti.csv]
2023-02-11 modelli separati gioco e scelte e modello unico, funziona il modello unico
    [Project3!.sdf, Project3!_Copy_01.sdf, data_register.csv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]
2023-02-12 modifica layout, tempi, staristiche, utente
    [data_register.csv]
2023-02-12 aggiunta README.txt
    [Project3!.sdf, Project3!_Copy_01.sdf, Project3.sdf]
2023-02-12 GUI con aggiunta di messaggi di errore e icona della batteria in tutte le schermate
    [data_register.csv]
2023-02-13 Codici commentato, ultime modifiche python con commenti
    [Project3.sdf, data_register.csv, dataset_test_GIOCO.csv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]

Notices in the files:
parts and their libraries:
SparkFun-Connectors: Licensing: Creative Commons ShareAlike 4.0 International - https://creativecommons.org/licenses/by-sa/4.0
